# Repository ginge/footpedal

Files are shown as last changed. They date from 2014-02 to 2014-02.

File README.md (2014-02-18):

footpedal
=========

3d printed foot pedal. Powered by Teensy 3. Has adjustable microswitch and potentiometer.

* Can send a configurable string of characters or both press and release
  - e.g. Press triggers CTRL-C Release triggers CTRL-V
* Supports all modifer keys (Crtl, ALt, Shift, Win etc)
  - As well as setting multiple keys at once
* supports key send on press and key release on release (for press CTRL etc)
  - Allows holding the key down
* has a pot for analogue joystick input (not fully implemented)
* daisy chainable pedals for up to 250 devices
  - Each device can be configured through one "master" device.
  - Each device can be the master device
  - You can have multiple masters... if you really want ?!?
* configurable keys sequences and options from QT application

Teensy config
=============

Pin setup:-

GND           - Pushbutton (any pin)
Digital 12    - Pushbutton (remaining pin)
A0 (Analogue) - Potentiometer centre pin
Pot end pin   - GND
Pot other end - +3.3V

--- to be documented!
RX1           - Serial connector
TX1
RX2
TX2

TODO:
Test multiple serial connected units.
Add automatic ID system
Add broadcast feature

Model and more description at
http://www.thingiverse.com/thing:249020

Barry Carter
Barry.carter@gmail.com

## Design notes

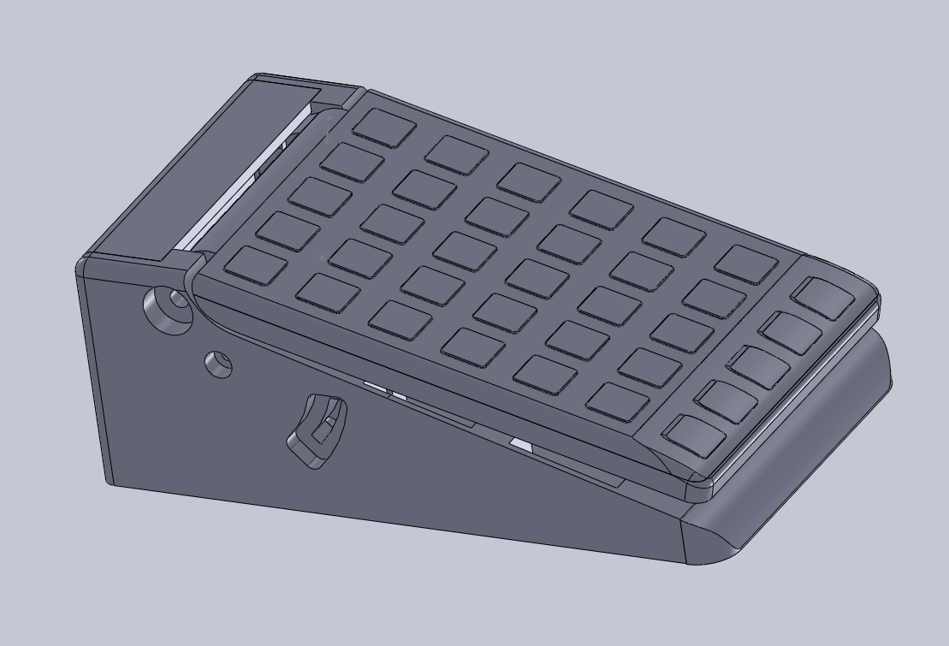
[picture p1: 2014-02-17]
Images/pedal 3d.png

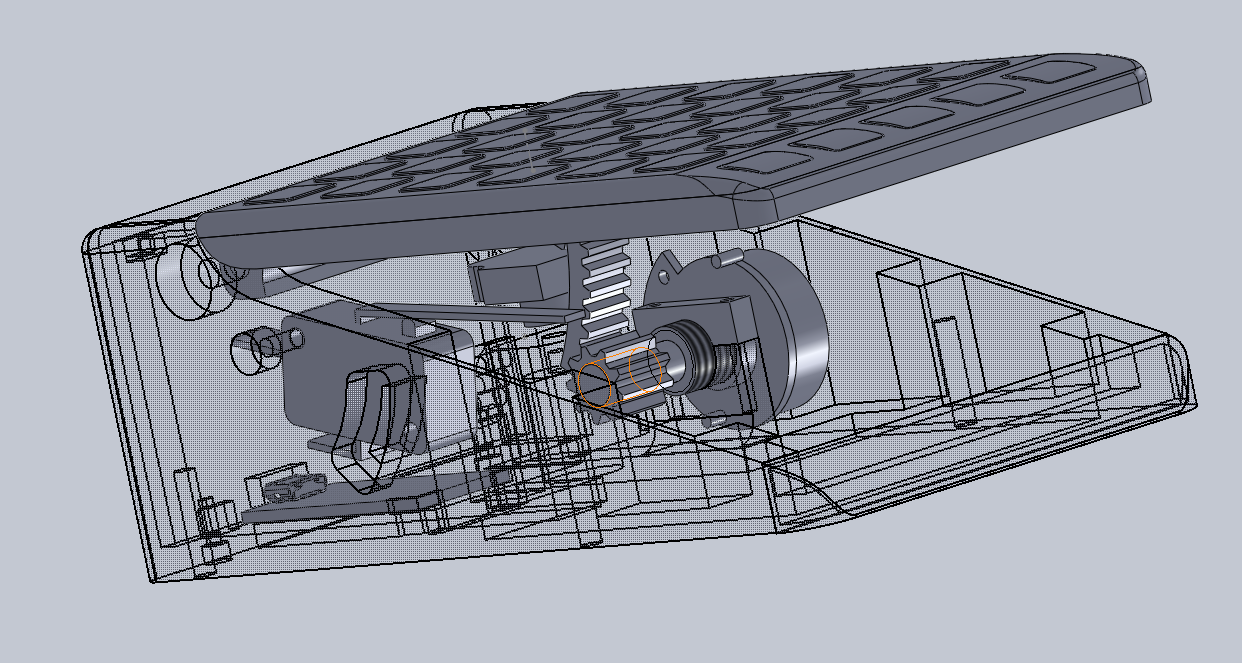
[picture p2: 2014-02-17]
Images/pedal innards.png

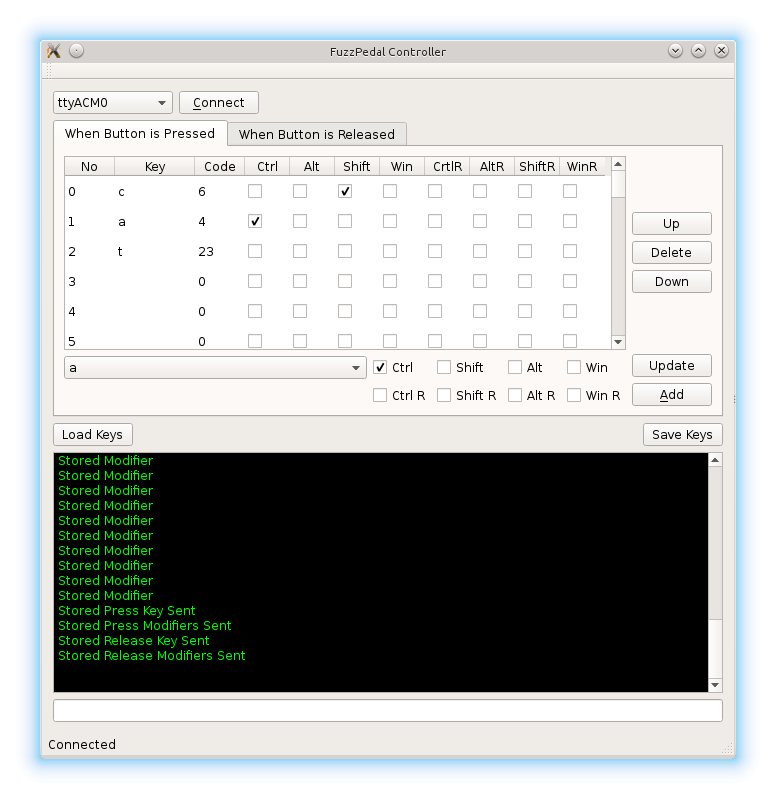
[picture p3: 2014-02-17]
Images/main app gui.png

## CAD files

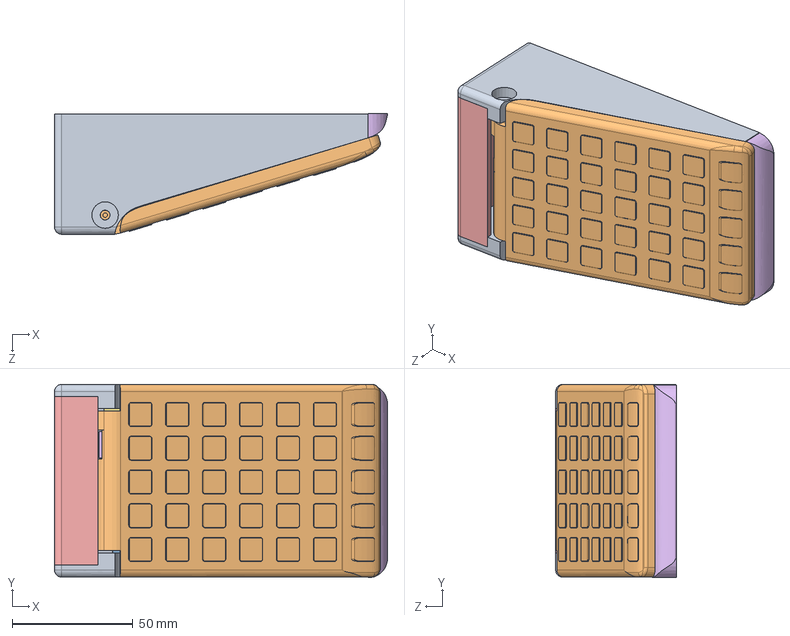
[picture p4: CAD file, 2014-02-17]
Foot Pedal Sld/pedal assm.SLDASM
138.1 x 80.2 x 50.1 mm
base
pedal
switchbody
button
lever
peg spring
spring cap
pot slide
pot
pot cog
pot clamp
teensy3.1
back panel
front panel

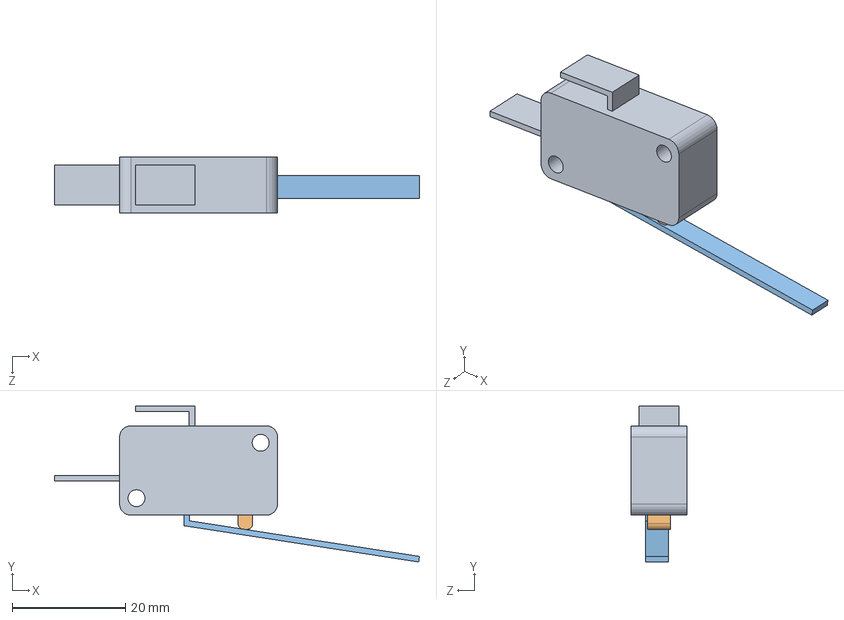
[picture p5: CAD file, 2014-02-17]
Foot Pedal Sld/microswitch/switch assm.SLDASM
64.5 x 27.6 x 9.95 mm
switchbody
button
lever

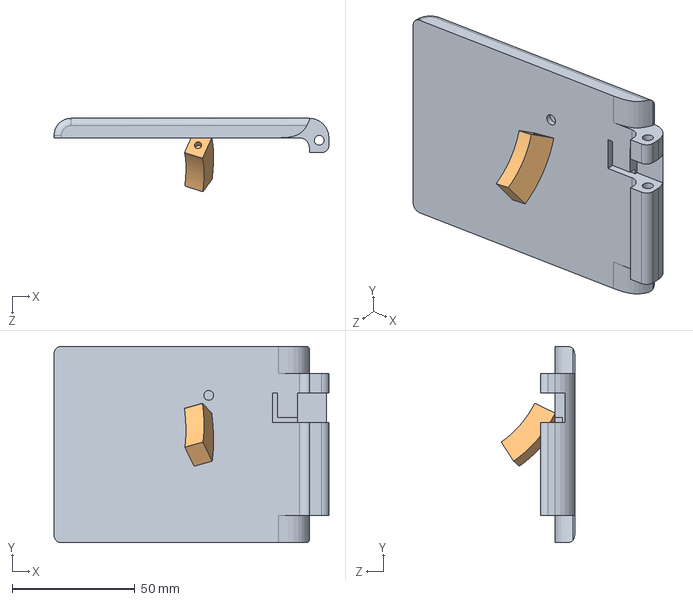
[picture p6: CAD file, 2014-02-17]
Foot Pedal Sld/pedal top.SLDASM
112.0 x 80.0 x 30.0 mm
pedal
pot slide

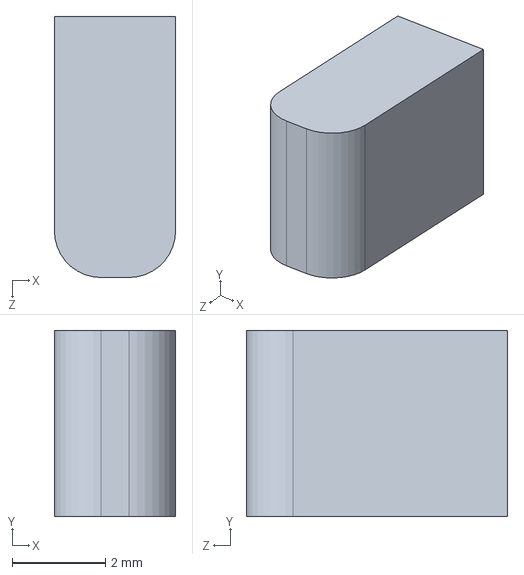
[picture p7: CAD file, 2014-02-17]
Foot Pedal Sld/microswitch/button.SLDPRT
2.60 x 4.00 x 5.60 mm

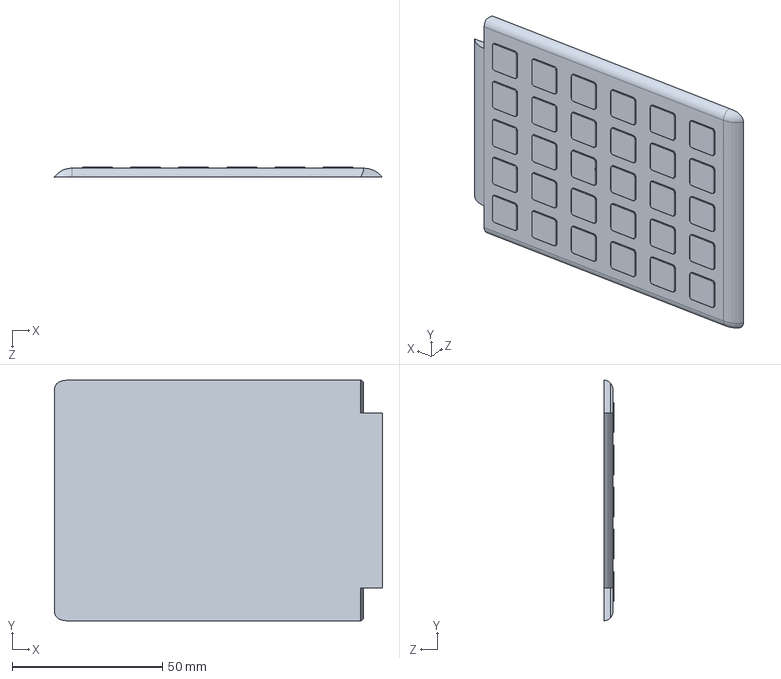
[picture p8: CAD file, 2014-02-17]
Foot Pedal Sld/pedal top plate.sldprt
109.0 x 80.0 x 3.40 mm

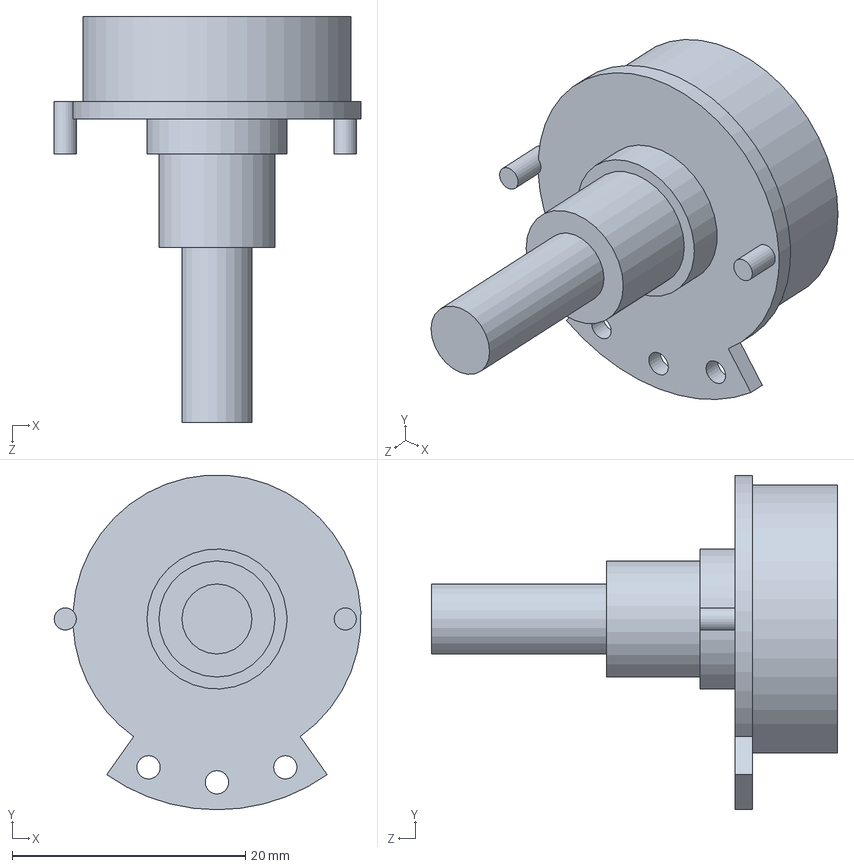
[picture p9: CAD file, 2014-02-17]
Foot Pedal Sld/pot/pot.SLDPRT
26.3 x 28.7 x 34.8 mm

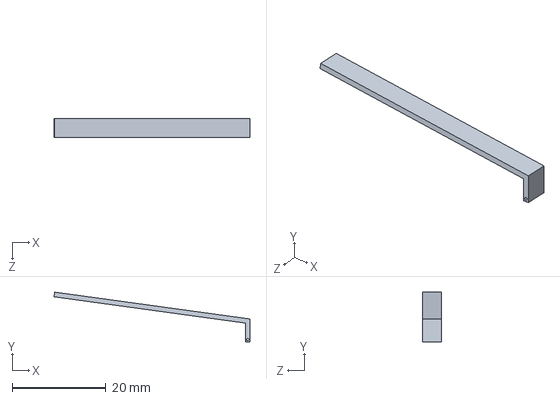
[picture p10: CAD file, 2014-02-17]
Foot Pedal Sld/microswitch/lever.SLDPRT
41.7 x 10.6 x 4.00 mm

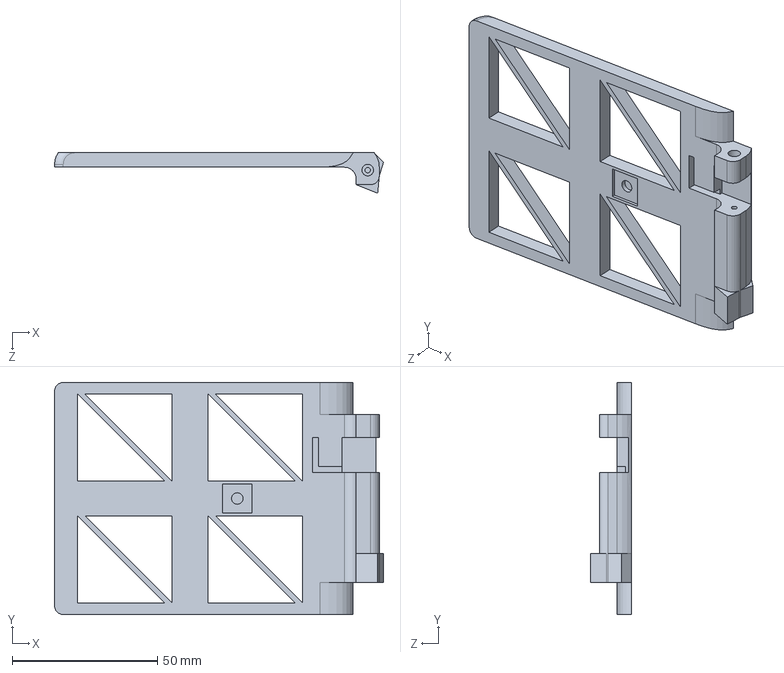
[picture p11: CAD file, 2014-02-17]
Foot Pedal Sld/pedal bottom.sldprt
113.4 x 80.0 x 14.0 mm

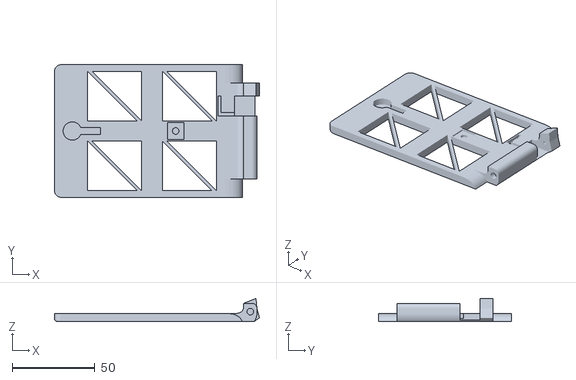
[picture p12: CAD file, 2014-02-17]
STL/pedal bottom.STL
123.5 x 80.0 x 14.0

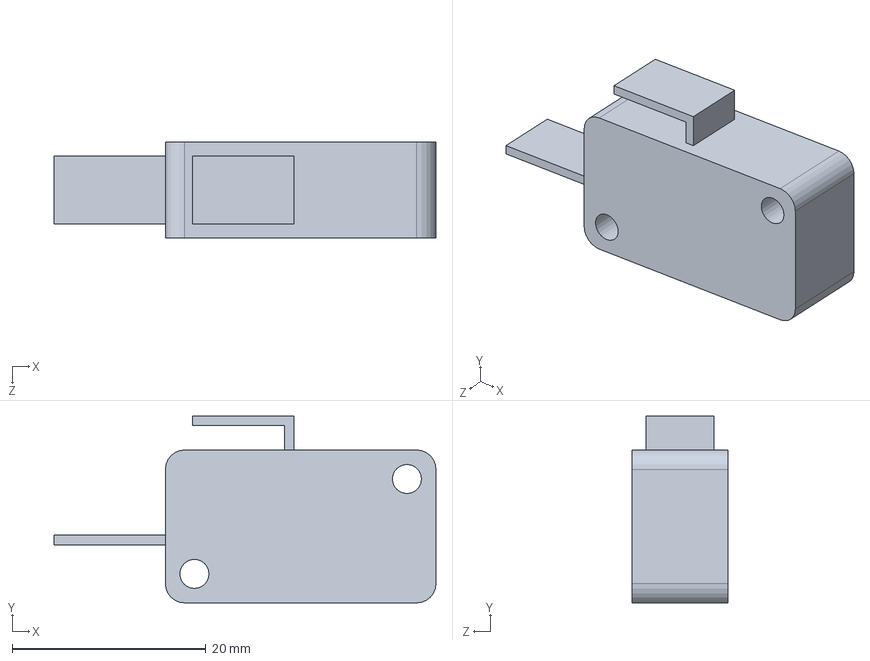
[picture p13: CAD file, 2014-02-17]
Foot Pedal Sld/microswitch/switchbody.SLDPRT
39.5 x 19.3 x 9.95 mm

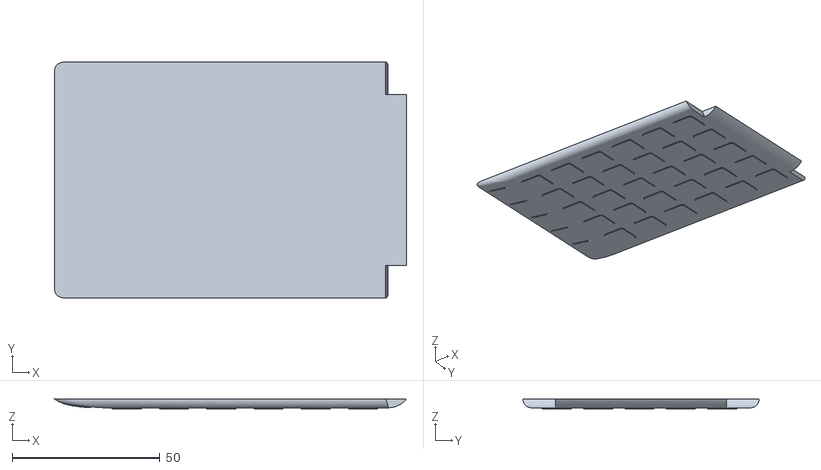
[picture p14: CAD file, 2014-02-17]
STL/pedal top plate.STL
119.2 x 80.0 x 3.40

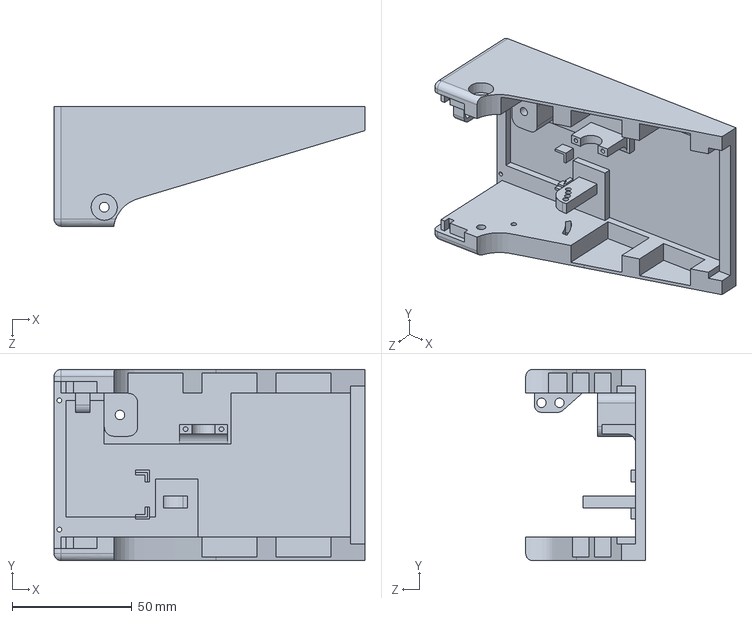
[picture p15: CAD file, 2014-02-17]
Foot Pedal Sld/base.SLDPRT
130.0 x 80.0 x 50.0 mm

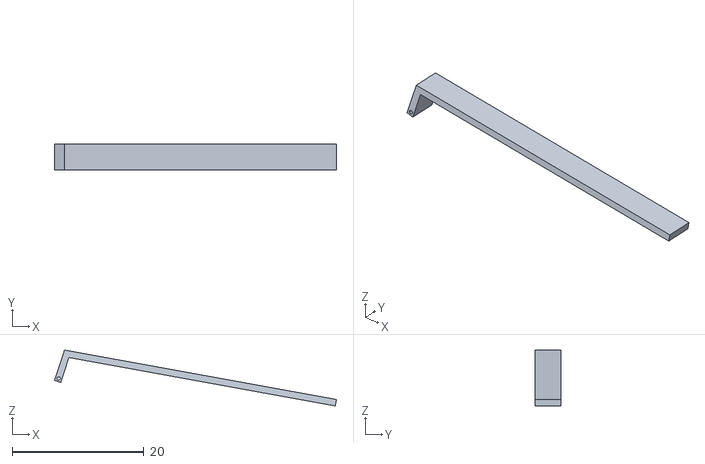
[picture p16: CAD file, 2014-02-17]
STL/pedal assm - switch assm-1 lever-1.STL
42.8 x 4.00 x 8.50

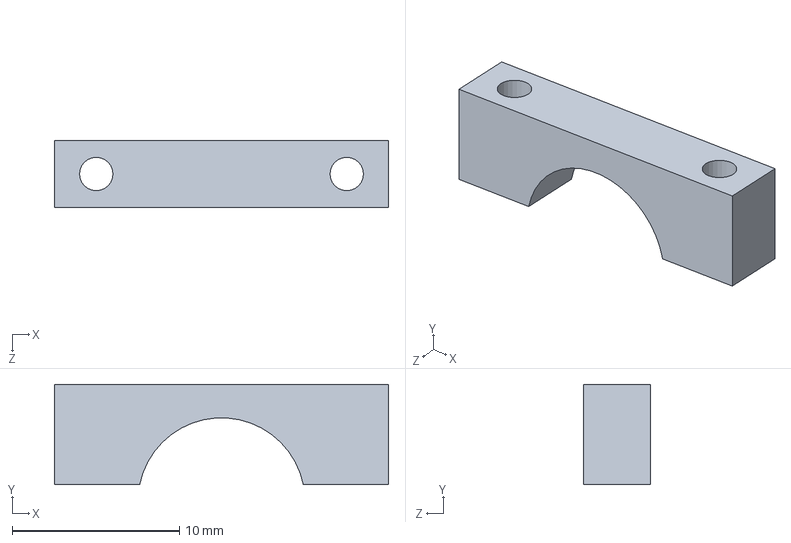
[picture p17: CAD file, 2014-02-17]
Foot Pedal Sld/pot clamp.SLDPRT
20.0 x 6.00 x 4.00 mm

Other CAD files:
STL/pedal assm - pot-1.STL
STL/pedal assm - switch assm-1 switchbody-1.STL
Foot Pedal Sld/pot cog.SLDPRT
STL/pedal assm - pot cog-1.STL
Foot Pedal Sld/back panel.SLDPRT
Foot Pedal Sld/front panel.SLDPRT
Foot Pedal Sld/pedal.SLDPRT
Foot Pedal Sld/peg spring.SLDPRT
Foot Pedal Sld/pot slide.SLDPRT
Foot Pedal Sld/spring cap.SLDPRT
STL/pedal assm - back panel-1.STL
STL/pedal assm - base-1.STL
STL/pedal assm - front panel-1.STL
STL/pedal assm - pedal-1.STL
STL/pedal assm - peg spring-1.STL
STL/pedal assm - pot clamp-1.STL
STL/pedal assm - pot slide-1.STL
STL/pedal assm - spring cap-1.STL
STL/pedal assm - switch assm-1 button-1.STL
STL/pedal assm - teensy3.1-1.STL
STL/pot slide.STL

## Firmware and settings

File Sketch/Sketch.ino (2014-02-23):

/*
  FuzzPedal foot pedal controller.
  Copyright (C) 2014  Barry Carter <barry.carter@gmail.com>
  
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
  You should have received a copy of the GNU General Public License
  along with this program; if not, write to the Free Software
  Foundation, Inc., 51 Franklin Street, Fifth Floor, Boston, MA  02110-1301, USA.
*/

#include <stdio.h>
#include <Bounce.h>
#include <EEPROM.h>

#define PIN_BUTTON_1  12  // digital 12
#define PIN_POT_1 0       // analogue 0

//globals
Bounce button1 = Bounce(PIN_BUTTON_1, 10);
elapsedMillis elapsedAnalogueReport;
elapsedMillis elapsedAnalogueRead;
int potValue = 0;

#define PACKET_TIMEOUT 5000   // ms before we bail on a packet
#define PACKET_SIZE 7       // number 8 bit elements in the packet

enum PACKET_FORMAT {
  ID_LOC = 0,
  SRC_LOC,
  CMD_LOC,
  DATA_LOC_0,
  DATA_LOC_1,
  DATA_LOC_A,
  DATA_LOC_A_1,
};

enum COMMANDS {
  CMD_JOYSTICK_X = 0,                  // We can send a joystick command
  CMD_JOYSTICK_Y,                      // For X or Y
  CMD_BUTTON1,                         // When the switch is pressed or released, we send some keystrokes
  CMD_BUTTON2,                         // second button not implemented yet
  CMD_SERIAL_USB,                      // button press send a serial command
  CMD_BUTTON_ON_PRESS,                 // button press send a keystroke, and holds it down
  CMD_BUTTON_ON_RELEASE,
  // Configuration section. Devices can send these commands to configure the pedal and keypresses
  CMD_CONFIGURE_ID = 30,
  CMD_CONFIGURE_BUT_CMD,
  CMD_CONFIGURE_BUT_KEY_PRESS,
  CMD_CONFIGURE_BUT_MODIFIER_PRESS,
  CMD_CONFIGURE_BUT_KEY_RELEASE,
  CMD_CONFIGURE_BUT_MODIFIER_RELEASE,
  CMD_CONFIGURE_POT_CMD,
  CMD_GET_ID = 50,
  CMD_GET_BUT_CMD,
  CMD_GET_POT_CMD,
  CMD_GET_POT_VALUE,
  CMD_CONFIGURE_GET_KEYS_PRESS,
  CMD_CONFIGURE_GET_MODIFIERS_PRESS,
  CMD_CONFIGURE_GET_KEYS_RELEASE,
  CMD_CONFIGURE_GET_MODIFIERS_RELEASE,
  CMD_CONFIGURE_SAVE,
  CMD_CONFIGURE_DEBUG_MSG = 70         // Sends a magic packet before sending serial data so the conf app doesn't break
};

enum SERIAL_PORTS {
  PORT_USB,
  PORT_SER1,
  PORT_SER2
};

// Our data packet structure to hold all packet info
typedef struct DataPackets {
  byte port;
  byte buffer[PACKET_SIZE];
  byte bytesReceived;
  elapsedMillis packetRecvTimer;
  byte nodeID;
  byte sourceID;
  byte command;
  int payload;
  int payloadExtra;
} DataPacket;
  
DataPacket packetSerial1;
DataPacket packetSerial2;
DataPacket packetSerialUSB;

// types of broadcast IDs
enum ID_TYPES {
  ID_UNCONFIGURED_SLAVE = 252,
  ID_BROADCAST_CHAIN1,
  ID_BROADCAST_CHAIN2,
  ID_BROADCAST_BOTH
};

// Configuration stuff
#define MAX_KEY_SEQ 10

struct {
  byte ID               = ID_UNCONFIGURED_SLAVE; // 255 is reserved for broadcast, 252 is a placeholder
  // change these lines below to have hard coded default key presses
  byte keyboardKeysPress[MAX_KEY_SEQ]        = {KEY_HOME, KEY_C, KEY_DELETE, KEY_V, 0};
  byte keyboardModifiersPress[MAX_KEY_SEQ]   = {KEY_LEFT_SHIFT, KEY_LEFT_CTRL, 0, KEY_LEFT_CTRL, 0};
  byte keyboardKeysRelease[MAX_KEY_SEQ]      = {KEY_H, KEY_A, KEY_H, KEY_A, 0};
  byte keyboardModifiersRelease[MAX_KEY_SEQ] = {0, 0, 0, 0};
  byte buttonCommand    = CMD_BUTTON1;       // function that is executed on button press
  byte potAxisCommand   = CMD_JOYSTICK_X;
  int  potSampleFreq    = 100;  //ms
  int  potReportFreq    = 1000;  //ms  
} Conf; 

// prototypes
void parseSerial(DataPacket *packet, byte data);
void sendDataType(DataPacket *packet);
void serialRelay(int destinationChain, DataPacket *packet);
void packetSend(DataPacket *packet, HardwareSerial *port);
void USBSend(DataPacket *packet);
void processOwnCommand(DataPacket *packet);
void saveEEPROM();

// go go go
void setup() {

  readEEPROM();
  
  // Setup the USB Serial
  Serial.begin(9600);
  
  // configure the joystick to manual send mode.  This gives precise
  // control over when the computer receives updates, but it does
  // require you to manually call Joystick.send_now().
  Joystick.useManualSend(true);
  
  // Enable pullups on switch inputs
  pinMode(PIN_BUTTON_1, INPUT_PULLUP);  // Switch connected to here

  // Start hardware serial ports
  Serial1.begin(9600);
  Serial2.begin(9600);

  // set the defaults
  packetSerial1.port = PORT_SER1;
  packetSerial2.port = PORT_SER2;
  packetSerialUSB.port = PORT_USB;
  packetSerial1.bytesReceived = 0;
  packetSerial2.bytesReceived = 0;
  packetSerialUSB.bytesReceived = 0;
  
  // initialise control over the keyboard:
  Keyboard.begin();
}

void loop() {

  checkPot();  
  checkButtons();
  checkSerial();
 
  // a brief delay, so this runs "only" 200 times per second
//  delay(5);
}

void checkPot() {
  
  // read the pot on the timer schedule
  if (elapsedAnalogueRead >= Conf.potSampleFreq) {
    elapsedAnalogueRead = elapsedAnalogueRead - Conf.potSampleFreq;
    potValue = analogRead(PIN_POT_1);
  }

  if (elapsedAnalogueReport >= Conf.potReportFreq) {
    elapsedAnalogueReport = elapsedAnalogueReport - Conf.potReportFreq;
  
    // send a fake data packet to ourselves for processing
    DataPacket packet;
    packet.command = Conf.potAxisCommand;
    packet.payload = potValue;
    packet.payloadExtra = 0;
    sendDataType(&packet);

#if 0
    char buffer[20];
    sprintf(buffer, "POT VALUE: %d", potValue);
    debugPrint(buffer);
#endif
  }
}

void checkButtons() {
  byte pressed = 0;
  byte rising = 0;
  
  // read the button states
  button1.update();
   
  // Button Pressed
  if (button1.fallingEdge()) {
    pressed = 1;
    Serial.println("Button Press");
  }
  
  // button released
  if (button1.risingEdge()) {
    pressed = 1;
    rising = 1;
    Serial.println("Button Release");
  }
  
  if (pressed) {
    // send a fake data packet to ourselves for processing
    DataPacket packet;
    packet.port = 0;
    packet.sourceID = Conf.ID;
    packet.nodeID = 0;
    for (int n=0;n < MAX_KEY_SEQ; n++) {
      if (!rising) {
        packet.command = Conf.buttonCommand;
        packet.payload = (int)Conf.keyboardKeysPress[n];
        packet.payloadExtra = Conf.keyboardModifiersPress[n];
      }
      else {
        packet.payload = (int)Conf.keyboardKeysRelease[n];
        packet.payloadExtra = Conf.keyboardModifiersRelease[n];
        
        // if we have the press command set, we need the next command to be a release
        if (Conf.buttonCommand == CMD_BUTTON_ON_PRESS)
        {
          packet.command = CMD_BUTTON_ON_RELEASE;
        }
      }
            
      sendDataType(&packet);
    }
  }

}

void checkSerial() {
  byte ch;
  // do the serial checks to see if there is data from the other slave
  // devices.
  // we have each device slaved using 2 uarts per device. The incoming data
  // has an ID which is checked. If the ID is 0, it is sent to the USB
  // if the ID doesn't match ours, it is sent through the other serial
  if (Serial1.available() > 0) {
    ch = Serial1.read();
    parseSerial(&packetSerial1, ch);
  }

  if (Serial2.available() > 0) {
    ch = Serial2.read();
    parseSerial(&packetSerial2, ch);
  }
  
  // check the host USB interface has any data for us
  if (Serial.available() > 0) {
    ch = Serial.read();
    parseSerial(&packetSerialUSB, ch);
  }
}


// build up a serial packet until we get a complete data packet
void parseSerial(DataPacket *packet, byte data) {
  
  //check for a timeout of a packet
  if (packet->packetRecvTimer >= PACKET_TIMEOUT) {
    packet->packetRecvTimer = 0;
    packet->bytesReceived = 0; // start again
  }  
  
  packet->buffer[packet->bytesReceived] = data;

  packet->bytesReceived++;

  if (packet->bytesReceived == PACKET_SIZE) {
    // we got the packet
    packet->nodeID = packet->buffer[ID_LOC];
    packet->sourceID = packet->buffer[SRC_LOC];
    packet->command = packet->buffer[CMD_LOC];

    // now do stuff with the packet
    packet->payload = packetToValue16(packet->buffer, DATA_LOC_0);
    packet->payloadExtra = packetToValue16(packet->buffer, DATA_LOC_A);
  
    if (packet->nodeID == ID_BROADCAST_BOTH ||
        packet->nodeID == ID_BROADCAST_CHAIN1 ||
        packet->nodeID == ID_BROADCAST_CHAIN2) {
      // this is a broadcast packet. we process and send this on regardless
      // It matched our ID! process it
      processOwnCommand(packet);
      // send the packet out the other Serial port(s)
      serialRelay(packet->nodeID, packet);
    }
    else if (packet->nodeID == Conf.ID) {
      // It matched our ID! process it!
      
      // NOTE:
      // 252 is used as a placeholder for the device ID. When a new slave is enabled, it
      // will have ID 252. The host will then scan, get the first 252 on the chain, and
      // then configure it.
      processOwnCommand(packet);
    }
    else {
      // send the packet out the other Serial port and USB
      serialRelay(ID_BROADCAST_BOTH, packet);
    }

    packet->bytesReceived = 0;
  }
}

// process a command sent to our ID
void processOwnCommand(DataPacket *packet) {
  switch (packet->command) {
    case CMD_CONFIGURE_BUT_KEY_PRESS:
      Conf.keyboardKeysPress[packet->payload] = packet->payloadExtra;
      break;
    case CMD_CONFIGURE_BUT_KEY_RELEASE:
      Conf.keyboardKeysRelease[packet->payload] = packet->payloadExtra;
      break;
    case CMD_CONFIGURE_BUT_MODIFIER_PRESS:
      Conf.keyboardModifiersPress[packet->payload] = packet->payloadExtra;
      break;
    case CMD_CONFIGURE_BUT_MODIFIER_RELEASE:
      Conf.keyboardModifiersRelease[packet->payload] = packet->payloadExtra;
      break;    
    case CMD_CONFIGURE_BUT_CMD:
      Conf.buttonCommand = packet->payload;
      break;
    case CMD_CONFIGURE_ID:
      Conf.ID = (int)(packet->payload);
      debugPrint("ID Updated");
      break;
    case CMD_CONFIGURE_POT_CMD:
      Conf.potAxisCommand = packet->payload;
      break;
      
    // now the getters
    case CMD_GET_ID:
      sendSerialData(packet->port, packet->sourceID, Conf.ID, CMD_GET_ID, Conf.ID, 0);
      debugPrint("Retured Device ID");
      break;
    case CMD_GET_BUT_CMD:
      sendSerialData(packet->port, packet->sourceID, Conf.ID, CMD_GET_BUT_CMD, Conf.buttonCommand, 0);
      break;
    case CMD_GET_POT_CMD:
      sendSerialData(packet->port, packet->sourceID, Conf.ID, CMD_GET_POT_CMD, Conf.potAxisCommand, 0);
      break;
    case CMD_GET_POT_VALUE:
      sendSerialData(packet->port, packet->sourceID, Conf.ID, CMD_GET_POT_VALUE, potValue, 0);
      break;
    case CMD_CONFIGURE_GET_KEYS_PRESS:
      for (int n = 0; n < MAX_KEY_SEQ; n++) {
         sendSerialData(packet->port, packet->sourceID, Conf.ID, CMD_CONFIGURE_GET_KEYS_PRESS, n, Conf.keyboardKeysPress[n]);
      }
      debugPrint("Stored Press Key Sent");
      break;
    case CMD_CONFIGURE_GET_MODIFIERS_PRESS:
      for (int n = 0; n < MAX_KEY_SEQ; n++) {
         sendSerialData(packet->port, packet->sourceID, Conf.ID, CMD_CONFIGURE_GET_MODIFIERS_PRESS, n, Conf.keyboardModifiersPress[n]);
      }
      debugPrint("Stored Press Modifiers Sent");
      break;
    case CMD_CONFIGURE_GET_KEYS_RELEASE:
      for (int n = 0; n < MAX_KEY_SEQ; n++) {
         sendSerialData(packet->port, packet->sourceID, Conf.ID, CMD_CONFIGURE_GET_KEYS_RELEASE, n, Conf.keyboardKeysRelease[n]);
      }
      debugPrint("Stored Release Key Sent");
      break;
    case CMD_CONFIGURE_GET_MODIFIERS_RELEASE:
      for (int n = 0; n < MAX_KEY_SEQ; n++) {
         sendSerialData(packet->port, packet->sourceID, Conf.ID, CMD_CONFIGURE_GET_MODIFIERS_RELEASE, n, Conf.keyboardModifiersRelease[n]);
      }
      debugPrint("Stored Release Modifiers Sent");
      break;
    case CMD_CONFIGURE_SAVE:
      saveEEPROM();
      debugPrint("Saved Settings");
      break;
  }
}

// send a command via serial/usb-serial/joystick or other
// this is the main function that is triggered on a button press
void sendDataType(DataPacket *packet) {
  
  switch (packet->command) {
    case CMD_JOYSTICK_X:
      Joystick.X(packet->payload);
      Joystick.send_now();
      break;
    case CMD_JOYSTICK_Y:
      Joystick.Y(packet->payload);
      Joystick.send_now();
      break;
    case CMD_BUTTON1:
      // send any control etc keys too
      if (packet->payloadExtra > 0) {
        Keyboard.set_modifier((byte)packet->payloadExtra);
      }
      else {
        Keyboard.set_modifier(0);
      }
      Keyboard.send_now();
      Keyboard.set_key1(packet->payload);
      Keyboard.send_now();
      delay(10);
      Keyboard.set_modifier(0);
      Keyboard.set_key1(0);
      Keyboard.send_now();
      break;
    case CMD_BUTTON2:
      Keyboard.print(packet->payload, BYTE);
      break;
    // Press and hold a key instead of sending a stream of chars
    case CMD_BUTTON_ON_PRESS:
      if (packet->payloadExtra > 0) {
        Keyboard.set_modifier((byte)packet->payloadExtra);
      }
      else {
        Keyboard.set_modifier(0);
      }
      Keyboard.send_now();
      Keyboard.set_key1(packet->payload);
      Keyboard.send_now();
      break;
    // release all keys
    case CMD_BUTTON_ON_RELEASE:
      Keyboard.set_modifier(0);
      Keyboard.set_key1(0);
      Keyboard.send_now();
      break;
    case CMD_SERIAL_USB:
      USBSend(packet);
  }
  
}

// send the packet to the other serial port(s)
void serialRelay(int destinationChain, DataPacket *packet) {
  // see where the packet came from.
  // if it comes from the USB host, send to both serial ports.
  // just in case we have chained devices on both sides
  // if it comes from one of the serial ports, we send it t the other
  // and/or USB port
  switch (destinationChain) {
    case ID_BROADCAST_BOTH:
      if (packet->port == PORT_SER1) { // we can't broadcast back to origin chain!
        packetSend(packet, &Serial2);
        USBSend(packet);
        debugPrint("Relayed broadcast from Chain 1 to USB + Chain 2");
      }
      else if (packet->port == PORT_SER2) { // we can't broadcast back to origin chain!
        packetSend(packet, &Serial1);
        USBSend(packet);
        debugPrint("Relayed broadcast from Chain 2 to USB + Chain 1");
      }
      else if (packet->port == PORT_USB && packet->nodeID == 0) { // it came from USB, and is destined for usb
        debugPrint("Relayed broadcast USB back to USB");
        USBSend(packet);
      }
      else {  // it must have come from the USB so relay over serial
        packetSend(packet, &Serial1);
        packetSend(packet, &Serial2);
        debugPrint("Relayed broadcast from USB to Chain 1 + Chain 2");
      }
      break;
   case ID_BROADCAST_CHAIN1:
      if (packet->port != PORT_SER1) { // we can't broadcast back to origin chain!
        packetSend(packet, &Serial1);
        debugPrint("Relayed Chain 1 Broadcast from Any to Chain 2");
      }
      break;
   case ID_BROADCAST_CHAIN2:
      if (packet->port != PORT_SER2) { // we can't broadcast back to origin chain!
        packetSend(packet, &Serial2);
        debugPrint("Relayed Chain 2 Broadcast from Any to Chain 1");
      }
      break;
   default:
      break;
  }
}

int packetToValue16(byte *buffer, int offset) {
  int val = 0;
  val |= buffer[offset];
  val = val << 8;
  val |= buffer[offset+1];
  
  return val;
}

void sendSerialData(int port, byte nodeTo, byte nodeFrom, byte command, int payload, int payloadExtra)
{
  DataPacket packet;
  packet.port = port;
  packet.nodeID = nodeTo;
  packet.sourceID = nodeFrom;
  packet.command = command;
  packet.payload = payload;
  packet.payloadExtra = payloadExtra;
  // send the new packet out over the relevant port
  serialRelay(ID_BROADCAST_BOTH, &packet);
}

void packetSend(DataPacket *packet, HardwareSerial *port) {
  // assemble the packet
  /*
  8 bits destination ID
  8 bits source ID
  8 bits command
  16 bits command data
  */ 
  cli();
  port->print(packet->nodeID, BYTE);
  port->print(packet->sourceID, BYTE);
  port->print(packet->command, BYTE);
  port->print((packet->payload >> 8) & 0xFF, BYTE);
  port->print(packet->payload & 0xFF, BYTE);
  port->print((packet->payloadExtra >> 8) & 0xFF, BYTE);
  port->print(packet->payloadExtra & 0xFF, BYTE);

  port->println();
  sei();
}

// annoying we need this, but the HardwareSerial and USBSerial classes are
// not compatible without lots of code. easier to replicate those few lines
void USBSend(DataPacket *packet) {
  cli();
  Serial.print(packet->nodeID, BYTE);
  Serial.print(packet->sourceID, BYTE);
  Serial.print(packet->command, BYTE);
  Serial.print((packet->payload >> 8) & 0xFF, BYTE);
  Serial.print(packet->payload & 0xFF, BYTE);
  Serial.print((packet->payloadExtra >> 8) & 0xFF, BYTE);
  Serial.print(packet->payloadExtra & 0xFF, BYTE);
  sei();
  //Serial.println();  
}

// sends a magic packet to the host before sending serial data. For compatibility with 
// a host side packet parser (config etc)
void debugPrint(const char str[]) {
  DataPacket packet;
  packet.command = CMD_CONFIGURE_DEBUG_MSG;
  packet.payload = 0;
  packet.payloadExtra = 0;
  USBSend(&packet);
  Serial.println(str);  
}

void saveEEPROM() {
  for (int i = 0; i < MAX_KEY_SEQ; i++) {
    // write the keypress contents in
    EEPROM.write(i, Conf.keyboardKeysPress[i]);
  }
  for (int i = MAX_KEY_SEQ; i < 2*MAX_KEY_SEQ; i++) {
    // write the keypress contents in
    EEPROM.write(i, Conf.keyboardModifiersPress[i-MAX_KEY_SEQ-1]);
  }
  for (int i = 2*MAX_KEY_SEQ; i < 3*MAX_KEY_SEQ; i++) {
    // write the keypress contents in
    EEPROM.write(i, Conf.keyboardKeysRelease[i-2*MAX_KEY_SEQ-1]);
  }
  for (int i = 3*MAX_KEY_SEQ; i < 4*MAX_KEY_SEQ; i++) {
    // write the keypress contents in
    EEPROM.write(i, Conf.keyboardModifiersRelease[i-3*MAX_KEY_SEQ-1]);
  }
  
  // save ID
  EEPROM.write(4*MAX_KEY_SEQ, Conf.ID);
  
  // save button command
  EEPROM.write((4*MAX_KEY_SEQ)+1, Conf.buttonCommand);
}

void readEEPROM()
{
  
  // load eeprom settings  
  for (int i = 0; i < MAX_KEY_SEQ; i++) {
    // read the keypress contents in
    Conf.keyboardKeysPress[i] = EEPROM.read(i);
  }
  for (int i = MAX_KEY_SEQ; i < 2*MAX_KEY_SEQ; i++) {
    // read the keypress contents in
    Conf.keyboardModifiersPress[i-MAX_KEY_SEQ-1] = EEPROM.read(i);
  }
  for (int i = 2*MAX_KEY_SEQ; i < 3*MAX_KEY_SEQ; i++) {
    // read the keypress contents in
    Conf.keyboardKeysRelease[i-2*MAX_KEY_SEQ-1] = EEPROM.read(i);
  }
  for (int i = 3*MAX_KEY_SEQ; i < 4*MAX_KEY_SEQ; i++) {
    // read the keypress contents in
    Conf.keyboardModifiersRelease[i-3*MAX_KEY_SEQ-1] = EEPROM.read(i);
  }
  // get ID
  Conf.ID =  EEPROM.read(4*MAX_KEY_SEQ);
  
  // get button command
  Conf.buttonCommand = EEPROM.read((4*MAX_KEY_SEQ)+1);
}

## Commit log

2014-02-18 Fixed up the sketch to allow press-release instead of sending spearate keystrokes. Qt app has preliminary support
    [Sketch.ino]
2014-02-18 Added pin connection info
2014-02-23 Fixed up some device->device comms. Cleaned up the sketch so comms are more reliable and relays are working Main Config application has lots of changes relating to updating the table. Added multiple 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
    [Sketch.ino]
2014-02-23 added inital pot reading and pot command setup in sketch and main config app the main app will poll the usb every 2 seconds and print the pot value
    The teensy will read the pot every x ms and reprot to USB every y ms
    TODO
    add pot averaging
    add host support for programming pot mode

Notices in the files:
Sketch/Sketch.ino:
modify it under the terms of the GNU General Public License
